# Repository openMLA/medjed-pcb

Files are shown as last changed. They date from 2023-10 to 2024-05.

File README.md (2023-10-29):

# Medjed Assembly

This repository contains the PCB files of the [MEDJED Maskless lithography system](https://github.com/openMLA/Medjed). PCB files are generated with KiCAD

Note that the [Wiki](https://github.com/openMLA/Medjed/wiki) and [Discussions](https://github.com/openMLA/Medjed/discussions) for the project are located in the main Medjed repository.

### Organisation

This repository should generally be obtained as a submodule of the main Medjed repository. That other repository will also have code and CAD files for the project.

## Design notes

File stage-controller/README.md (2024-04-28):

## Medjed Stage

The controller board for the Medjed stage is built around a Teensy 4.1, Snapmaker linear axes and external RLC2IC encoders. The signal of the encoders is processed and converted to step/dir signals for the snapmaker axes by Trinamic `TMC4631`

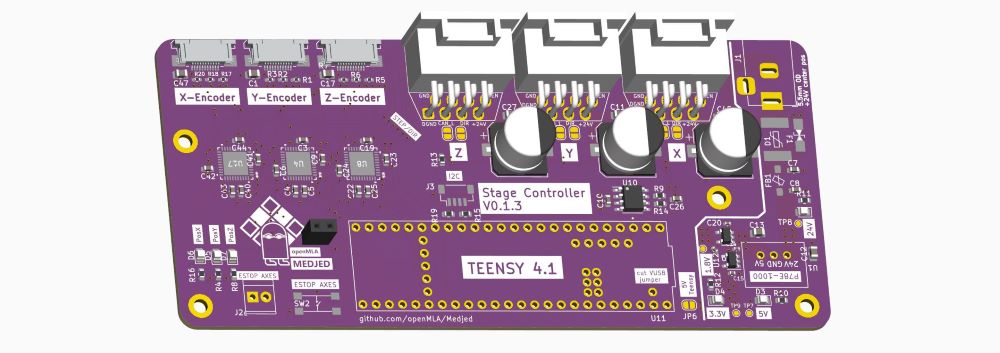
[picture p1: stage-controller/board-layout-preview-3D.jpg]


### I2C Connection

A STEMMA-QT connector (JST SH, 4 pin) is present on the board for any I2C peripherals. A planned connection would be a UV sensor to be fitted on the stage that will serve as stage calibration. 

### CAN Bus

The Snapmaker linear axes use a CAN bus to talk to the MCU inside the axes (reporting on endstop status and such). It would be quite inefficient to put a CAN transceiver for each of the axes, but running them as part of a single CAN bus means we need to go slightly outside of recommended CAN bus parameters. 

The cables for the linear axes are 40cm, and I assume that the transmission line is terminated with 120Ohm impedance. Running three terminated nodes may prove to be too much for the transceiver to power. In addition, the 40cm cable length is a little over the recommended max length for CAN nodes. I think both concerns are not fundamentally unworkable. The bus speed may need to be reduced to compensate, but this shouldn't really be an issue for the targeted application.

> Future designs should probably expose a CAN bus for other peripherals to be connected; or to handle communication with devices on the Z-axi.

### Safety

The Emergency Stop (`ESTOP`) signal is controllable from the teensy, but features manual trigger in the form of a simple PCB switch and a terminal for external switches. 

> Future revisions will need a proper EMO switch that kills power to all systems (axes and optics)

### Power considerations

The snapmaker linear axes use 24V supply. The snapmaker power supply comes with plenty of overhead in terms of power (as it need to be able to run a 3D printer heated bed) so that is not a concern. 

We also need 5V and 3.3V supply on the board.

5V:

* Teensy 4.1: 100mA
* [3X] RLC2IC encoders: <30mA (no termination resistors) or <130mA with 120ohm termination.

3.3V:

* TMC4631: ???

1.8V:

* TMC4631: ???

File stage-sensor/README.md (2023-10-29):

## Chuck Sensor PCB

This PCB is designed to fit into the sample chuck of the MEDJED system. It contains the following 3 sensors:

* A temperature and humidity sensor
* An accelerometer and gyroscope 
* A UV sensor

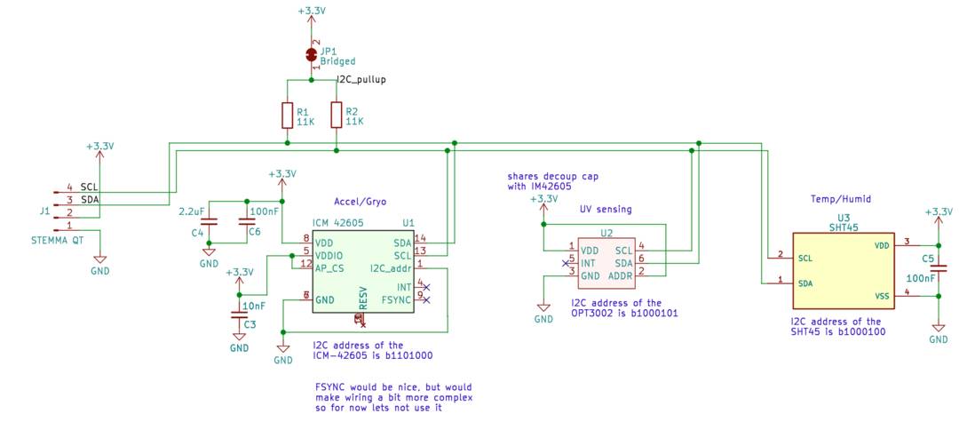
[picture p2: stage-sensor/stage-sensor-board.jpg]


### UV sensor

The OPT3002 Light sensor will be useful to calibrate and correct for UV intensity of the illumination and projection system. The sensing area is smaller than the projected area, so some stage movement and averaging tricks will have to be applied. 

Some fiducial crosses and silkscreen markings have been added to help automation efforts and the finding of the IC when manually moving the stage around

### Temperature and Humidity sensor

The SHT45 temperature and humidity sensor is just for logging purposes. Changes in temperature and humidity can affect the photoresist and development process, so having a record of this is useful.

### Accelerometer and Gyroscope

The ICM42605 accelerometer and gyroscope unit can serve two purposes:

1. Get a feel for stage movement and apply input shaping to increase movement and settling speed (low priority)
2. Determine when the stage has settled and we are ready to expose an image.

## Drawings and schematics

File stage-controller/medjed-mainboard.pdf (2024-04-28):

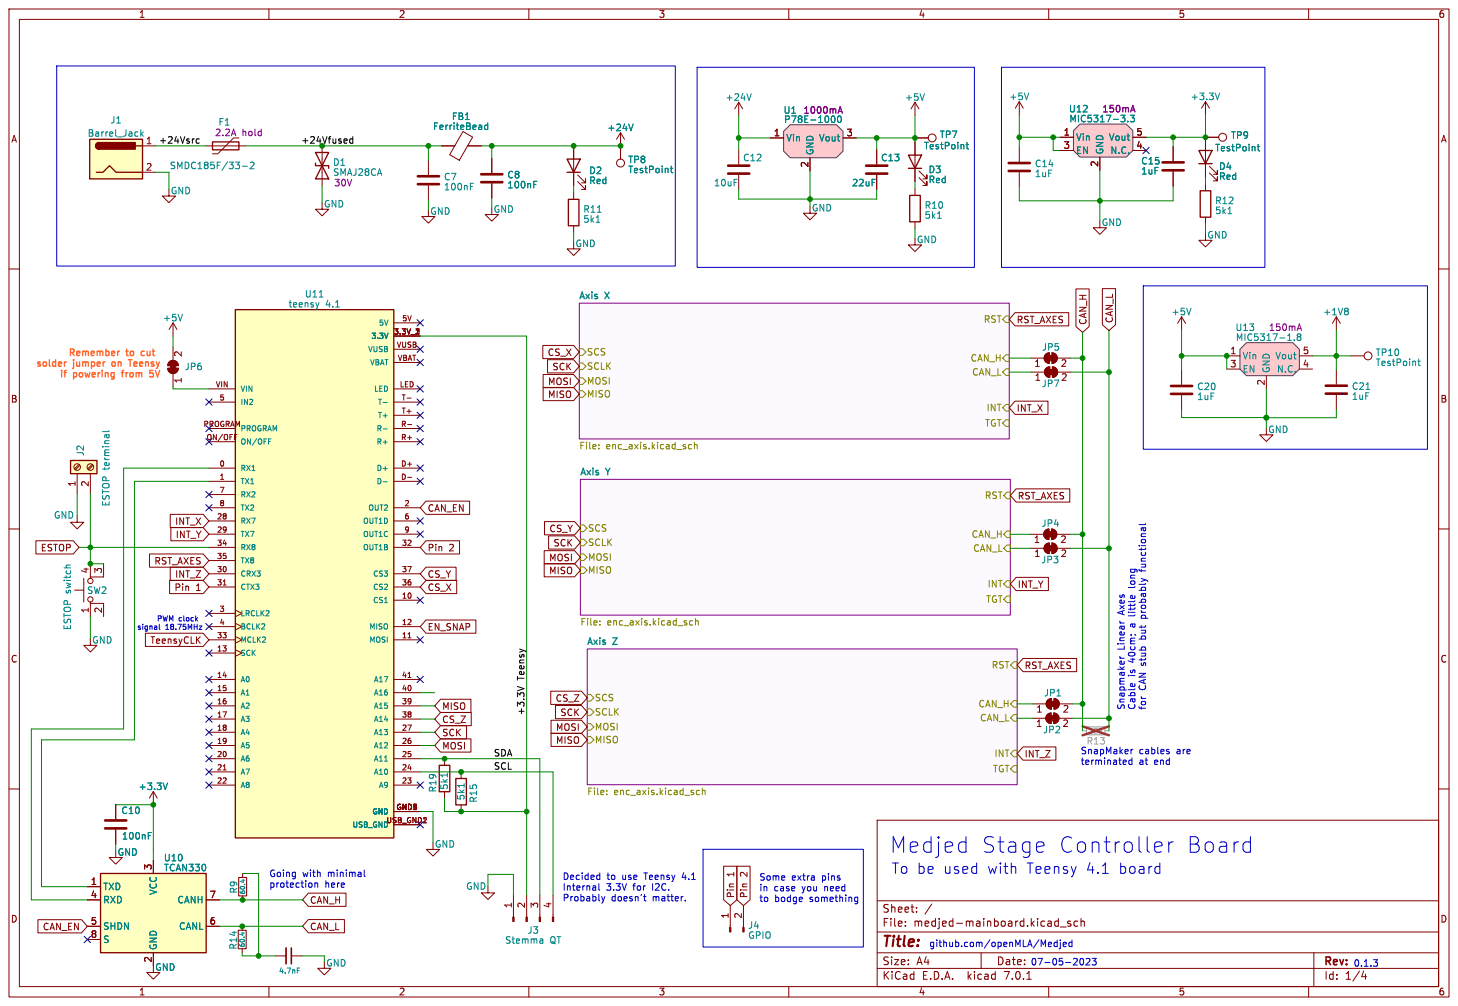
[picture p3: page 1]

2 EN 3 N.C. 4 Vout 5 TP9 TestPoint D4 Red

2 J2 ESTOP terminal GND GND

Remember to cut solder jumper on Teensy

VBAT VBAT VIN VIN

07-05-2023 To be used with Teensy 4.1 board

3 RXD 4 SHDN 5 CANL 6 CANH 7 S

to bodge something Decided to use Teensy 4.1

in case you need

github.com/openMLA/Medjed

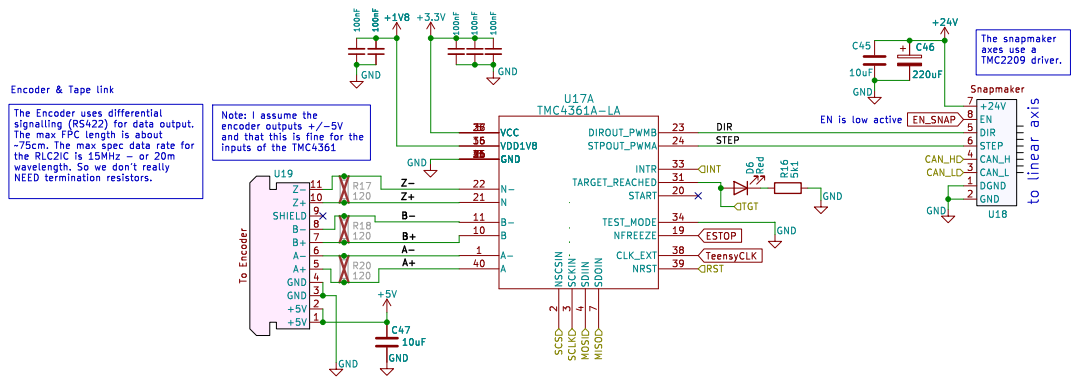
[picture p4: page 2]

encoder outputs +/-5V
and that this is fine for the

Id: 2/4 Title: File: enc_axis.kicad_sch Sheet: /Axis X/ C47

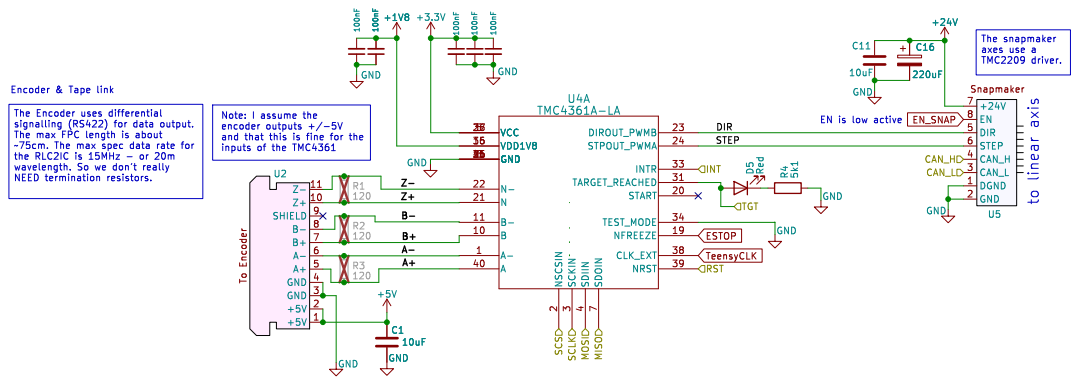
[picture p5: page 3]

encoder outputs +/-5V
and that this is fine for the

10uF GND
Id: 3/4 Title: File: enc_axis.kicad_sch Sheet: /Axis Y/ GND

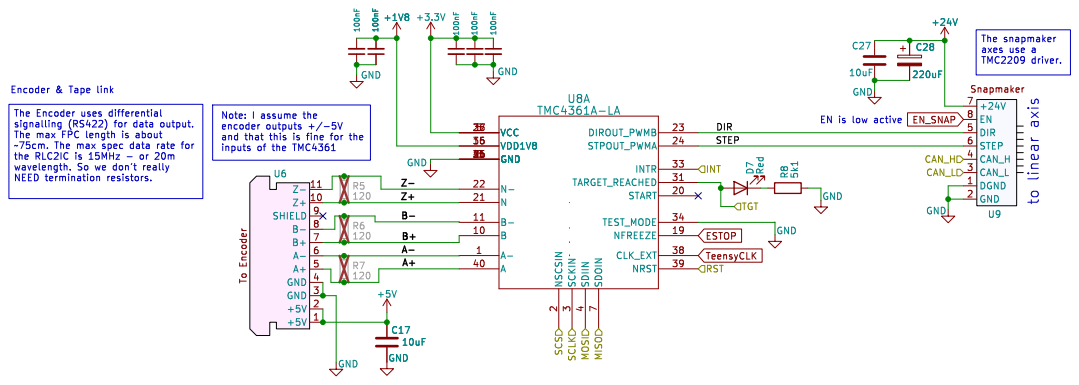
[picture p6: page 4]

encoder outputs +/-5V
and that this is fine for the

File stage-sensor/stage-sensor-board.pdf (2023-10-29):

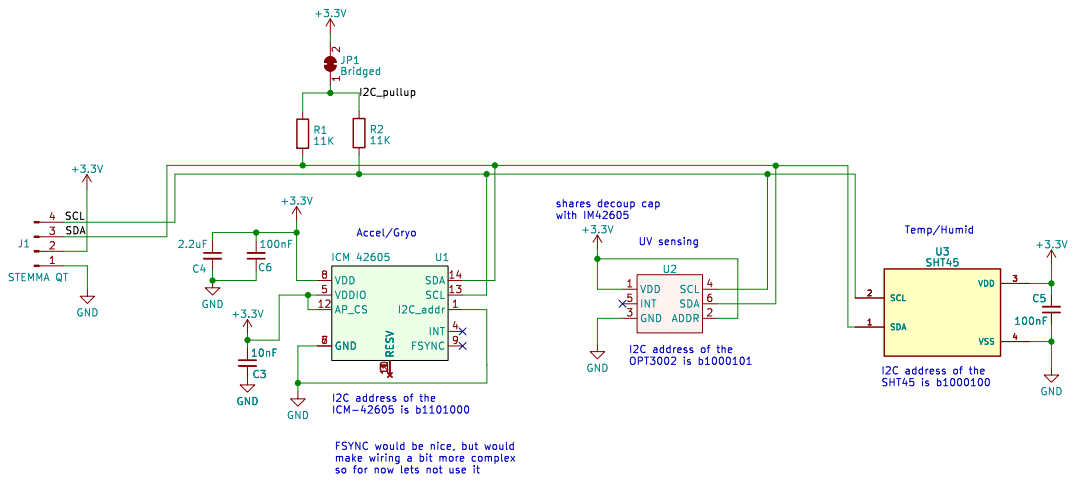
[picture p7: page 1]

1 2 JP1 Bridged VDD 1 ADDR 2 GND 3 SCL 4

shares decoup cap with IM42605 Accel/Gryo

I2C address of the SHT45 is b1000100 Temp/Humid UV sensing

I2C address of the OPT3002 is b1000101

so for now lets not use it

Id: 1/1 Title: File: stage-sensor-board.kicad_sch Sheet: /

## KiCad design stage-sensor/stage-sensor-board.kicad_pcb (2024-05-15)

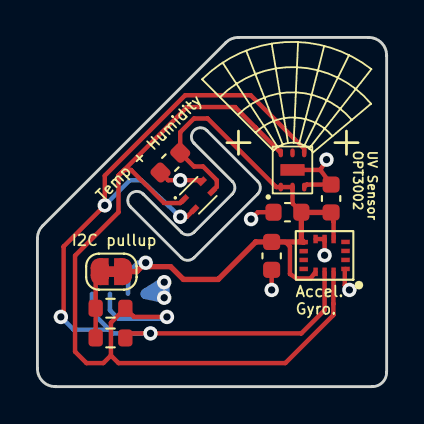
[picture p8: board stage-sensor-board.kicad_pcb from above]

Board: 2 copper layers, 19.4 x 19.4 mm, 11 parts (1 on the bottom side), 5 nets.

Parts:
C3: 10nF; C_0603_1608Metric
C4: 2.2uF; C_0603_1608Metric
C5, C6: 100nF; C_0603_1608Metric
J1: STEMMA QT; JST_SH_SM04B-SRSS-TB_1x04-1MP_P1.00mm_Horizontal
JP1: Bridged; SolderJumper-2_P1.3mm_Bridged_RoundedPad1.0x1.5mm
R1, R2: 11K; R_0603_1608Metric
U1: ICM 42605; icm-42605
U2: OPT3002
U3: SHT45; SHT4X

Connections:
+3.3V: C3.1, C4.1, C5.2, C6.2, J1.2, JP1.2 (B), U1.5 (VDDIO), U1.8 (VDD), U1.12 (AP_CS), U2.1 (VDD), U2.2 (ADDR), U3.3 (VDD)
/I2C_pullup: JP1.1 (A), R1.1, R2.1
/SCL: J1.4, R2.2, U1.13 (SCL), U2.4 (SCL), U3.2 (SCL)
/SDA: J1.3, R1.2, U1.14 (SDA), U2.6 (SDA), U3.1 (SDA)
GND: C3.2, C4.2, C5.1, C6.1, J1.1, U1.1 (I2C_addr), U1.6 (GND), U1.7 (GND), U2.3 (GND), U3.4 (VSS)

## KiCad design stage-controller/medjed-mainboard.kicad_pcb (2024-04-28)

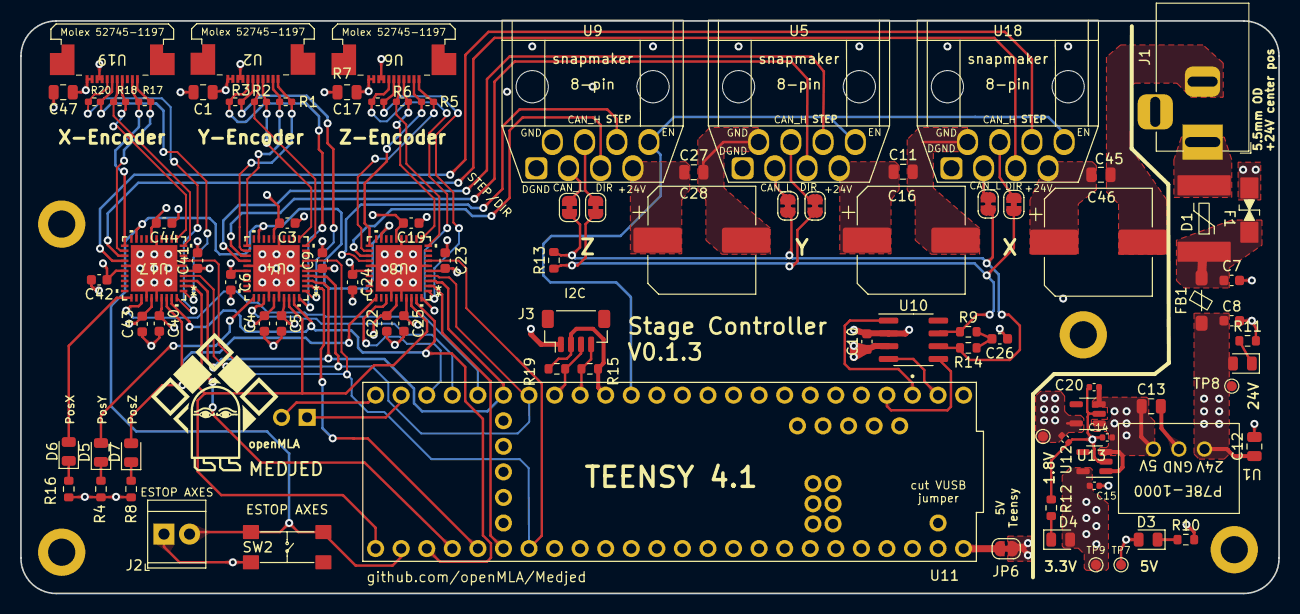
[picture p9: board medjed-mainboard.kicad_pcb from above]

Board: 4 copper layers, 125.0 x 56.9 mm, 93 parts (0 on the bottom side), 71 nets.

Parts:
C1, C11, C12, C17, C27, C45, C47: 10uF; C_0805_2012Metric
C3, C4, C5, C6, C7, C8, C9, C10, C19, C22, C23, C24, C25, C40, C41, C42, C43, C44: 100nF; C_0603_1608Metric
C13: 22uF; C_0805_2012Metric
C14, C15, C20, C21: 1uF; C_0402_1005Metric
C16, C28, C46: 220uF; CP_Elec_220uf
C26: 4.7nF; C_0603_1608Metric
D1: SMAJ28CA
D2, D3, D4, D5, D6, D7: Red; LED_0805_2012Metric
F1: SMDC185F/33-2; SMDC185F_33-2
FB1: FerriteBead; BLM41P600S
J1: Barrel_Jack; BarrelJack_Horizontal
J2: ESTOP terminal; TerminalBlock_TE_282834-2_1x02_P2.54mm_Horizontal
J3: Stemma QT; JST_SH_BM04B-SRSS-TB_1x04-1MP_P1.00mm_Vertical
J4: GPIO; PinSocket_1x02_P2.54mm_Vertical
JP1, JP2, JP3, JP4, JP5, JP6, JP7: SolderJumper_2_Bridged; SolderJumper-2_P1.3mm_Bridged_RoundedPad1.0x1.5mm
R1, R2, R3, R5, R6, R7, R17, R18, R20: 120; R_0402_1005Metric_Pad0.72x0.64mm_HandSolder
R4, R8, R10, R11, R12, R15, R16, R19: 5k1; R_0603_1608Metric
R9, R14: 60.4; R_0603_1608Metric
R13: 120; R_0603_1608Metric
SW2: ESTOP switch; E-switch-button
TP7, TP8, TP9, TP10: TestPoint; TestPoint_Pad_D1.0mm
U1: P78E-1000
U2, U6, U19: Molex 52745-1197
U4, U8, U17: TMC4361A-LA; TMC4361A_QFN40_6X6_TRI
U5, U9, U18: snapmaker_8-pin
U10: TCAN330; SOIC-8_3.9x4.9mm_P1.27mm
U11: teensy 4.1; teensy_4.1
U12: MIC5317-3.3; SOT-23-5
U13: MIC5317-1.8; SOT-23-5

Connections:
+1V8: C3.2, C4.2, C19.2, C21.1, C22.2, C43.2, C44.2, TP10.1, U4.16 (VDD1V8), U4.35 (VDD1V8), U8.16 (VDD1V8), U8.35 (VDD1V8), U13.5 (Vout), U17.16 (VDD1V8), U17.35 (VDD1V8)
+3.3V: C5.1, C6.1, C9.1, C10.1, C15.1, C23.1, C24.1, C25.1, C40.1, C41.1, C42.1, D4.2 (A), TP9.1, U4.5 (VCC), U4.26 (VCC), U4.37 (VCC), U8.5 (VCC), U8.26 (VCC), U8.37 (VCC), U10.3 (VCC), U12.5 (Vout), U17.5 (VCC), U17.26 (VCC), U17.37 (VCC)
+5V: C1.1, C13.1, C14.1, C17.1, C20.1, C47.1, D3.2 (A), JP6.2 (B), TP7.1, U1.3 (Vout), U2.1 (+5V), U2.2 (+5V), U6.1 (+5V), U6.2 (+5V), U12.1 (Vin), U12.3 (EN), U13.1 (Vin), U13.3 (EN), U19.1 (+5V), U19.2 (+5V)
+24V: C8.1, C11.1, C12.1, C16.1, C27.1, C28.1, C45.1, C46.1, D2.2 (A), FB1.2, TP8.1, U1.1 (Vin), U5.7 (+24V), U9.7 (+24V), U18.7 (+24V)
/+3.3V Teensy: J3.2, R15.1, R19.1, U11.3.3V_1 (3.3V), U11.3.3V_2 (3.3V), U11.3.3V_3 (3.3V)
/+24Vfused: C7.1, D1.2 (A2), F1.2, FB1.1
/+24Vsrc: F1.1, J1.1
/Axis X/A+: R20.2, U17.40 (A), U19.5 (A+)
/Axis X/A-: R20.1, U17.1 (A-), U19.6 (A-)
/Axis X/B+: R18.2, U17.10 (B), U19.7 (B+)
/Axis X/B-: R18.1, U17.11 (B-), U19.8 (B-)
/Axis X/CAN_H: JP5.1 (A), U18.4 (CAN_H)
/Axis X/CAN_L: JP7.1 (A), U18.3 (CAN_L)
/Axis X/DIR: U17.23 (DIROUT_PWMB), U18.5 (DIR)
/Axis X/STEP: U17.24 (STPOUT_PWMA), U18.6 (STEP)
/Axis X/TGT: D6.2 (A), U17.31 (TARGET_REACHED)
/Axis X/Z+: R17.2, U17.21 (N), U19.10 (Z+)
/Axis X/Z-: R17.1, U17.22 (N-), U19.11 (Z-)
/Axis Y/A+: R3.2, U2.5 (A+), U4.40 (A)
/Axis Y/A-: R3.1, U2.6 (A-), U4.1 (A-)
/Axis Y/B+: R2.2, U2.7 (B+), U4.10 (B)
/Axis Y/B-: R2.1, U2.8 (B-), U4.11 (B-)
/Axis Y/CAN_H: JP4.1 (A), U5.4 (CAN_H)
/Axis Y/CAN_L: JP3.1 (A), U5.3 (CAN_L)
/Axis Y/DIR: U4.23 (DIROUT_PWMB), U5.5 (DIR)
/Axis Y/STEP: U4.24 (STPOUT_PWMA), U5.6 (STEP)
/Axis Y/TGT: D5.2 (A), U4.31 (TARGET_REACHED)
/Axis Y/Z+: R1.2, U2.10 (Z+), U4.21 (N)
/Axis Y/Z-: R1.1, U2.11 (Z-), U4.22 (N-)
/Axis Z/A+: R7.2, U6.5 (A+), U8.40 (A)
/Axis Z/A-: R7.1, U6.6 (A-), U8.1 (A-)
/Axis Z/B+: R6.2, U6.7 (B+), U8.10 (B)
/Axis Z/B-: R6.1, U6.8 (B-), U8.11 (B-)
/Axis Z/CAN_H: JP1.1 (A), U9.4 (CAN_H)
/Axis Z/CAN_L: JP2.1 (A), U9.3 (CAN_L)
/Axis Z/DIR: U8.23 (DIROUT_PWMB), U9.5 (DIR)
/Axis Z/STEP: U8.24 (STPOUT_PWMA), U9.6 (STEP)
/Axis Z/TGT: D7.2 (A), U8.31 (TARGET_REACHED)
/Axis Z/Z+: R5.2, U6.10 (Z+), U8.21 (N)
/Axis Z/Z-: R5.1, U6.11 (Z-), U8.22 (N-)
/SCL: J3.4, R15.2, U11.24 (A10)
/SDA: J3.3, R19.2, U11.25 (A11)
CAN_EN: U10.5 (SHDN), U11.2 (OUT2)
CAN_H: JP1.2 (B), JP4.2 (B), JP5.2 (B), R9.1, R13.1, U10.7 (CANH)
CAN_L: JP2.2 (B), JP3.2 (B), JP7.2 (B), R13.2, R14.2, U10.6 (CANL)
CS_X: U11.36 (CS2), U17.2 (NSCSIN)
CS_Y: U4.2 (NSCSIN), U11.37 (CS3)
CS_Z: U8.2 (NSCSIN), U11.38 (A14)
EN_SNAP: U5.8 (EN), U9.8 (EN), U11.12 (MISO), U18.8 (EN)
ESTOP: J2.2, SW2.3 (K), SW2.4 (A), U4.19 (NFREEZE), U8.19 (NFREEZE), U11.34 (RX8), U17.19 (NFREEZE)
GND: C1.2, C3.1, C4.1, C5.2, C6.2, C7.2, C8.2, C9.2, C10.2, C11.2, C12.2, C13.2, C14.2, C15.2, C16.2, C17.2, C19.1, C20.2, C21.2, C22.1, C23.2, C24.2, C25.2, C26.1, C27.2, C28.2, C40.2, C41.2, C42.2, C43.1, C44.1, C45.2, C46.2, C47.2, D1.1 (A1), J1.2, J2.1, J3.1, R4.2, R8.2, R10.2, R11.2, R12.2, R16.2, SW2.1, U1.2 (GND), U2.3 (GND), U2.4 (GND), U4.6 (GND), U4.15 (GND), U4.25 (GND), U4.34 (TEST_MODE), U4.36 (GND), U4.41 (GND), U5.1 (DGND), U5.2 (GND), U6.3 (GND), U6.4 (GND), U8.6 (GND), U8.15 (GND), U8.25 (GND), U8.34 (TEST_MODE), U8.36 (GND), U8.41 (GND), U9.1 (DGND), U9.2 (GND), U10.2 (GND), U11.GND1 (GND), U11.GND2 (GND), U11.GND3 (GND), U11.GND4 (GND), U11.GND5 (GND), U12.2 (GND), U13.2 (GND), U17.6 (GND), U17.15 (GND), U17.25 (GND), U17.34 (TEST_MODE), U17.36 (GND), U17.41 (GND), U18.1 (DGND), U18.2 (GND), U19.3 (GND), U19.4 (GND)
INT_X: U11.28 (RX7), U17.33 (INTR)
INT_Y: U4.33 (INTR), U11.29 (TX7)
INT_Z: U8.33 (INTR), U11.30 (CRX3)
MISO: U4.7 (SDOIN), U8.7 (SDOIN), U11.39 (A15), U17.7 (SDOIN)
MOSI: U4.4 (SDIIN), U8.4 (SDIIN), U11.26 (A12), U17.4 (SDIIN)
unnamed: C26.2, R9.2, R14.1
unnamed: D2.1 (K), R11.1
unnamed: D3.1 (K), R10.1
unnamed: D4.1 (K), R12.1
unnamed: D5.1 (K), R4.1
unnamed: D6.1 (K), R16.1
unnamed: D7.1 (K), R8.1
unnamed: JP6.1 (A), U11.VIN
unnamed: U10.4 (RXD), U11.0 (RX1)
unnamed: U10.1 (TXD), U11.1 (TX1)
Pin 1: J4.1, U11.31 (CTX3)
Pin 2: J4.2, U11.32 (OUT1B)
RST_AXES: U4.39 (NRST), U8.39 (NRST), U11.35 (TX8), U17.39 (NRST)
SCK: U4.3 (SCKIN), U8.3 (SCKIN), U11.27 (A13), U17.3 (SCKIN)
TeensyCLK: U4.38 (CLK_EXT), U8.38 (CLK_EXT), U11.33 (MCLK2), U17.38 (CLK_EXT)

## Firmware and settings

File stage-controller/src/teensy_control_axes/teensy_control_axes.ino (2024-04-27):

// written for use on Teensy 4.1
#include <SPI.h>  // include the SPI library:

const int CS_X = 36;
const int CS_Y = 37;
const int CS_Z = 38;
const int clkPin = 33;

void setup() {
  Serial.println("\n\nSetting up the TMC4361 axes...\n\n");

  // set the slaveSelectPin as an output:
  pinMode (CS_X, OUTPUT);
  pinMode (CS_Y, OUTPUT);
  pinMode (CS_Z, OUTPUT);

  digitalWrite(CS_X,HIGH);  // make sure X axis is OFF
  digitalWrite(CS_Y,HIGH);  // make sure Y axis is OFF
  digitalWrite(CS_Z,HIGH);  // make sure Z axis is OFF

  int32_t ext_clock_freq = 18750000;
  analogWriteFrequency(clkPin, ext_clock_freq);  // try to get 18.75MHz clock signal out for TMC4361
  analogWrite(clkPin, 128);
  Serial.println("External clock signal for TMC4631 set...");

  delay(500);  // wait a bit for the TMC4361 to figure itself out.

  SPISettings spi_settings(2000000, MSBFIRST, SPI_MODE3); 

  // initialize SPI:
  SPI1.setMISO(39);
  SPI1.begin(); 
  SPI1.setMISO(39);
  SPI1.beginTransaction(spi_settings);
  Serial.println("\n\nSPI hardware initialised...\n\n");
  
  check_SPI(CS_X);
  check_SPI(CS_Y);
  check_SPI(CS_Z);

  int CS_ACTIVE = CS_X;

  // set up motion axis X
  configure_axis(CS_ACTIVE);

  // write nonzero target position
  // byte target_data[] = {0x37, 0b00000000, 0x00, 0x04, 0xFF};  // signed 32 bit (so max 2^31)
  // write_spi(CS_ACTIVE, target_data);
  set_position(CS_ACTIVE, 1200);

  for (int i = 1; i < 10; i++) {
    print_position(CS_ACTIVE);
    delay(200);
  }

  // write nonzero target position (warning: stage moves)
  set_position(CS_ACTIVE, -1400);

  for (int i = 1; i < 40; i++) {
    print_position(CS_ACTIVE);
    delay(200);
  }
}

void loop() {
  
  delay(5000);
}

void configure_axis(int CS_pin) {
  /// Set up axis to the point where the move commands can be called

  // Set up the correct external clock speed
  // important to have velocity be in "physically accurate" steps/time 
  write_spi(CS_pin, 0x31, 0x11E11A30);  // see ext_clock_freq. Claimed to be 24:0 but that cannot be right? doesnt fit values

  // zero position position and target
  write_spi(CS_pin, 0x21, 0);  // position
  write_spi(CS_pin, 0x37, 0);  // target

  // extend the pulsewidth for the step/dir signals
  write_spi(CS_pin, 0x10, 0x00000000 + 0b00001111);  // set STEP duration to be 15 clock cycles, instead of just 1 

  // write ramp mode
  write_spi(CS_pin, 0x20, 0x00000000 + 0b00000101); // POSITION mode, with trapezoidal ramp

  // set max acceleration/deceleration
  write_spi(CS_pin, 0x28, 0x0000FFFF); // 23:0 are relevant
  write_spi(CS_pin, 0x29, 0x0000FFFF);

  // set max velocity
  write_spi(CS_pin, 0x24, 0x0002FF00); // 31:0 are relevant, 23 digits, 8 decimal places

  delay(200);  // can be removed, but means the POS=TARGET led will be lit for a bit
}

signed long get_position(int CS_pin) {
  return read_spi(CS_pin, 0x21);
}

void print_position(int CS_pin) {
  Serial.printf("Position is: %ld\n", get_position(CS_pin));
  Serial.printf("Position is: %x\n", get_position(CS_pin));
}

void set_position(int CS_pin, signed long position) {
  Serial.printf("> Moving axis %d to position %ld...\n",  CS_pin, position);
  write_spi(CS_pin, 0x37, position);
}

void check_SPI(int CS_pin) {
  /// checks if the TMC4361 at the CS_pin is giving the expected response.
  /// 
  /// It is recommend that you call this function before any SPI communication as the first response
  /// over SPI is nonsense or something. Anyway, this should make sure SPI is ready and working before
  /// you start going serious work over that serial interface.

  unsigned long response = read_spi(CS_pin, 0x00);  // read the general register (0x00)
  
  if (response == 0x00006020) {
    printf("SPI communication with CS %d is OK!\n", CS_pin);
  } else {
    printf("Did not get expected response over SPI for CS %d\n", CS_pin);
  }
}

unsigned long read_spi(int CS_pin, byte spi_register) {
  // first we must write the register we want to read
  digitalWrite(CS_pin,LOW);  

  SPI1.transfer(spi_register);
  for (int i = 1; i < 5; i++) {
    SPI1.transfer(0x00);
  } 

  // take the SS pin high to de-select the chip:
  digitalWrite(CS_pin,HIGH); 

  // and now we can read out the actual values. We send the same query, but we could pick any valid register.
  return read_spi_single(CS_pin, spi_register);
}

unsigned long read_spi_single(int CS_pin, byte spi_register) {

  unsigned long response;

  digitalWrite(CS_pin,LOW);  
  delayMicroseconds(10);

  SPI1.transfer(spi_register);
  for (int i = 1; i < 4; i++) {
    response |= SPI1.transfer(0x00);
    //Serial.printf("got response (same cycle): %x\n", response);
    response <<= 8;
  } 
  response |= SPI1.transfer(0x00);  // dont need a bit shift after last byte

  // take the SS pin high to de-select the chip:
  digitalWrite(CS_pin,HIGH);

  return response;
}

void write_spi(int CS_pin, byte address, unsigned long data) {
  //TMC4361 takes 5-byte bit data: 8 address and 32 data

  //Serial.printf("\nWriting SPI data %x to register %x\n", data, address);

  digitalWrite(CS_pin,LOW);
  delayMicroseconds(10);

  // to send write request we add 0b10000000 to the equivalent read address
  SPI1.transfer(address + 0x80);  // address
  SPI1.transfer((data >> 24) & 0xff);
  SPI1.transfer((data >> 16) & 0xff);
  SPI1.transfer((data >> 8) & 0xff);
  SPI1.transfer((data) & 0xff);
  digitalWrite(CS_pin,HIGH);

  // and we read back the value to check that it was set correctly
  unsigned long readback = read_spi_single(CS_pin, address);

  // compare values
  if (readback != data) {
    Serial.printf("> SPI write mismatch: read %x but expected %x \n", readback, data);
  }
}

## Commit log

2023-10-29 Intial commit after splitting into separate repository
    Used to be part of Medjed, but after reorganisation it will be a separate repository. History is still avaialable in archived version of medjed repository. Check out Medjed repository for more inform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
    [enc_axis.kicad_sch, medjed-mainboard.kicad_pcb, medjed-mainboard.kicad_sch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]
2023-10-29 Update schematic preview jpg
2024-02-10 fix silkscreen error
    Silkscreen labelled the 1.8V net as 1.5V, which is confusing. Fixed by editing the silkscreen label.
    [medjed-mainboard.kicad_pcb]
2024-02-13 fix Teensy 4.1 footprint
    Original footprint had through hole pads that were too small (0.8mm diameter). New ones are bigger to accomodate common pin headers.
    [medjed-mainboard.kicad_pcb]
2024-04-27 Fix Clock pin and MISO/MOSI error
    The TeensyCLK signal was routed to a pin on the Teensy 4.1 that did not support PWM. Now fixed. MOSI and MISO of SPI interface were flipped around by mistake. Now in correct orientation and should allow SPI communication (tested with messy wiring).
    [enc_axis.kicad_sch, medjed-mainboard.kicad_pcb, medjed-mainboard.kicad_sch]
2024-04-27 Add basic stage code for teensy
    Simple code with a few basic abstractions. Still needs a good homing procedure and does not use the encoder interface.
2024-04-28 Removed differential line receivers
    During design of the board I did not realise that the TMC4631 already has this built in (I had different motion controllers before). So the AM26LS32A ICs should not be needed. Removed these and rerou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
    [enc_axis.kicad_sch, medjed-mainboard.kicad_pcb, medjed-mainboard.kicad_sch]
2024-05-15 Stage sensor board V0.1.1
    Switched out the vertical stemma QT for horizontal one. Funciontally equivalent to V0.1.1 WIll send this one over for production.
    [stage-sensor-board.kicad_pcb, stage-sensor-board.kicad_sch]
